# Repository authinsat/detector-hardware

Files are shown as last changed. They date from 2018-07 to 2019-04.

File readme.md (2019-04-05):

#American University ThinSat repository

American University Physics Department
Washington, DC

##Synopsis
This is the support repository for AU's ThinSat project, embarked upon in Spring 2018. Supported by VASpace, Twiggs Space Laboratories, XinaBox, the DC NASA Space Grant Consortium, and the Institute for Integrated Space Science and Technology (ISSTI).

Currently, the only materials housed in this repository are the PCB design files for the particle detector.

Initial PCB design from MIT's Cosmic Watch <https://github.com/spenceraxani/CosmicWatch-Desktop-Muon-Detector-v2>.

This project is licensed under the MIT License; please see license.md for more information.

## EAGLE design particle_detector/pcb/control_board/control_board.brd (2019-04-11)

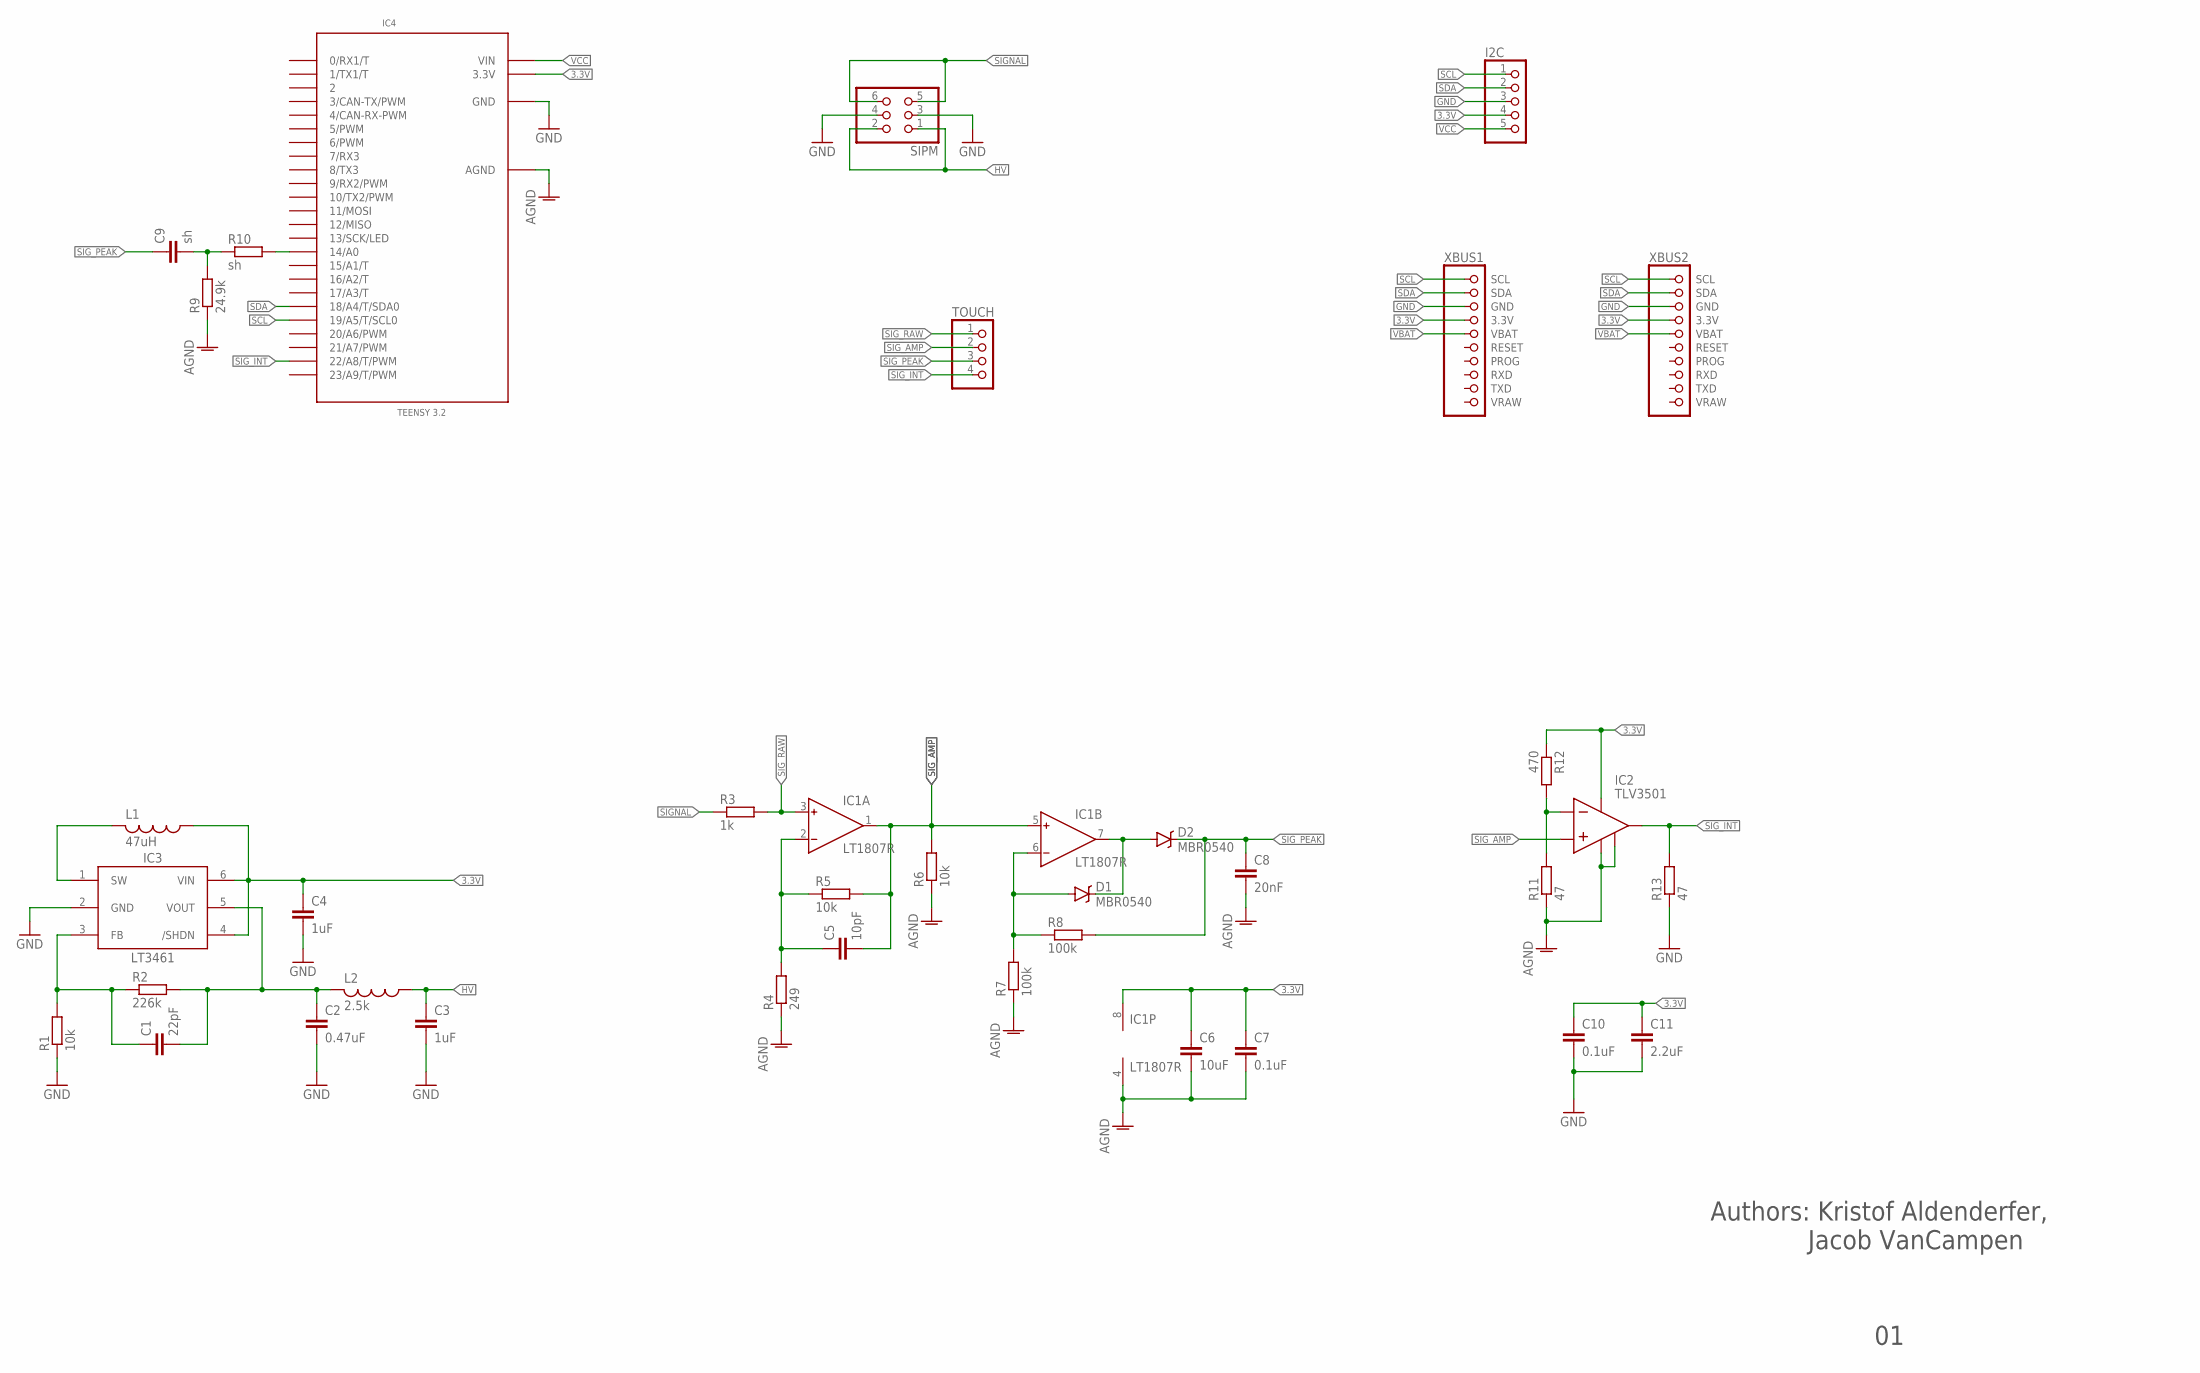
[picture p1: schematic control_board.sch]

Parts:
C1: 22pF; C0805K
C2: 0.47uF; C0805K
C3, C4: 1uF; C0805K
C5: 10pF; C0805K
C6: 10uF; C0805K
C7: 0.1uF; C0805K
C8: 20nF; C0805K
C9: sh; C0805K
C10: 0.1uF; C0805
C11: 2.2uF; C0805
D1, D2: MBR0540; SMA-DIODE
I2C: PINHD-1X5; 1X05
IC1: LT1807R; SO8
IC2: TLV3501; SOT23-6
IC3: LT3461; SOT23-6
IC4: TEENSY 3.2; TEENSY_3.2_NO_BOTTOM
L1: 47uH; L3225M
L2: 2.5k; L2012C
R1, R5, R6: 10k; M0805
R2: 226k; M0805
R3: 1k; M0805
R4: 249; M0805
R7, R8: 100k; M0805
R9: 24.9k; M0805
R10: sh; M0805
R11, R13: 47; M0805
R12: 470; M0805
SIPM: PINHD-2X3; 2X03
TOUCH: PINHD-1X4; 1X04
XBUS1, XBUS2: XINABOX-XBUS; XBUS_2X05_PAD

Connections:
3.3V: C4.1, C6.1, C7.1, C10.1, C11.1, I2C.4, IC1.8 (V+), IC2.P$4 (V+), IC3.4 (/SHDN), IC3.6 (VIN), IC4.3.3V, L1.1, R12.1, XBUS1.VCC (3.3V), XBUS2.VCC (3.3V)
AGND: C6.2, C7.2, C8.2, IC1.4 (V-), IC2.P$2 (V-), IC2.P$6 (SHDN), IC4.AGND, R4.1, R6.1, R7.1, R9.1, R11.1
GND: C2.2, C3.2, C4.2, C10.2, C11.2, I2C.3, IC3.2 (GND), IC4.GND, R1.1, R13.1, SIPM.3, SIPM.4, XBUS1.GND, XBUS2.GND
HV: C3.1, L2.1, SIPM.1, SIPM.2
unnamed: IC3.1 (SW), L1.2
unnamed: D1.C, D2.A, IC1.7 (OUT)
unnamed: C1.1, IC3.3 (FB), R1.2, R2.1
unnamed: D1.A, IC1.6 (IN-), R7.2, R8.1
unnamed: IC2.P$1 (IN-), R11.2, R12.2
unnamed: C1.2, C2.1, IC3.5 (VOUT), L2.2, R2.2
unnamed: C5.1, IC1.2 (IN-), R4.2, R5.1
unnamed: C9.2, R9.2, R10.1
unnamed: IC4.14/A0, R10.2
SCL: I2C.1, IC4.19/A5 (19/A5/T/SCL0), XBUS1.SCL, XBUS2.SCL
SDA: I2C.2, IC4.18/A4 (18/A4/T/SDA0), XBUS1.SDA, XBUS2.SDA
SIGNAL: R3.1, SIPM.5, SIPM.6
SIG_AMP: C5.2, IC1.1 (OUT), IC1.5 (IN+), IC2.P$3 (IN+), R5.2, R6.2, TOUCH.2
SIG_INT: IC2.P$5 (OUT), IC4.22/A8 (22/A8/T/PWM), R13.2, TOUCH.4
SIG_PEAK: C8.1, C9.1, D2.C, R8.2, TOUCH.3
SIG_RAW: IC1.3 (IN+), R3.2, TOUCH.1
VBAT: XBUS1.VBAT, XBUS2.VBAT
VCC: I2C.5, IC4.VIN

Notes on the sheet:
Authors: Kristof Aldenderfer, Jacob VanCampen

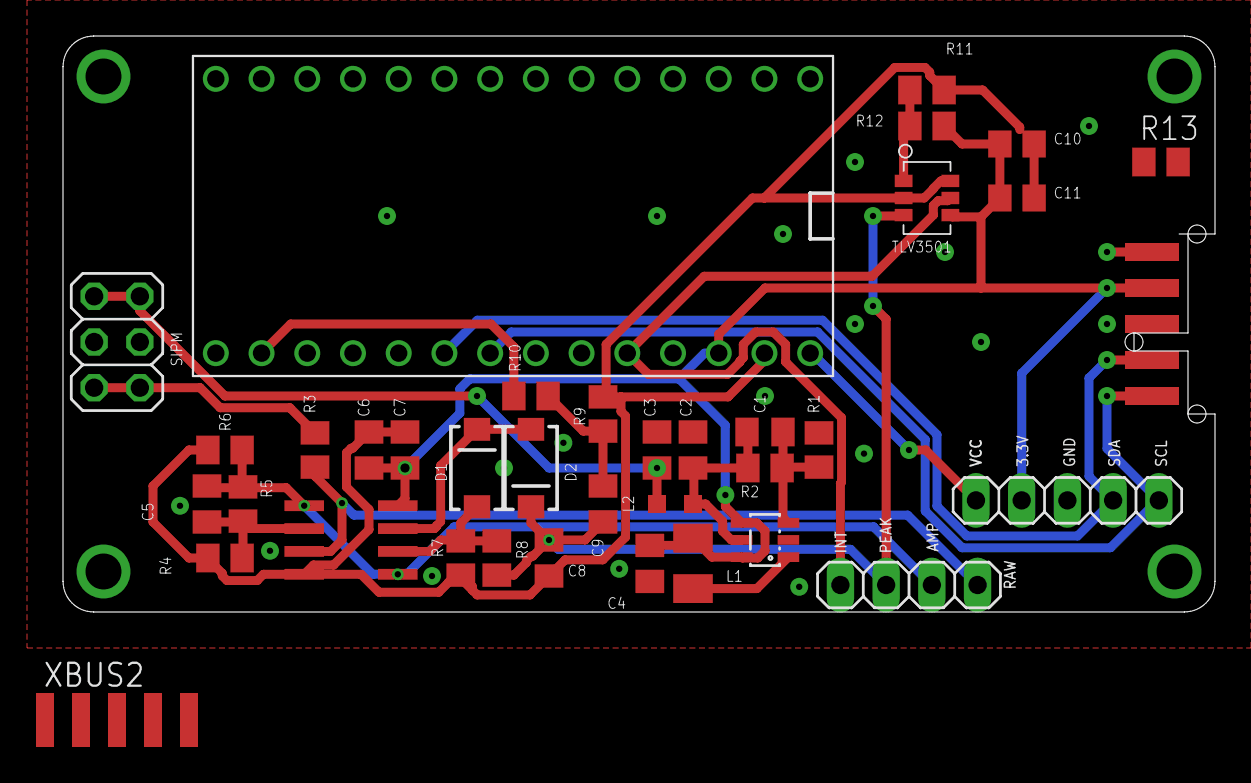
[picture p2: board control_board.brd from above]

Board: 2 copper layers, 64.0 x 32.0 mm, 37 parts (0 on the bottom side), 22 nets.

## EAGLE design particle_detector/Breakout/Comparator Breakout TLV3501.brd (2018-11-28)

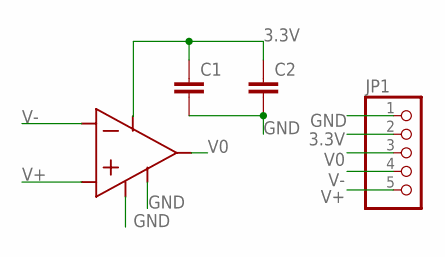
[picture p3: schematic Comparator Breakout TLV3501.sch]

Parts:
C1, C2: C-EUC0805; C0805
JP1: PINHD-1X5; 1X05
U$1: TLV3501; SOT23-6

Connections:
3.3V: C1.1, C2.1, JP1.2, U$1.P$4 (V+)
GND: C1.2, C2.2, JP1.1, U$1.P$2 (V-), U$1.P$6 (SHDN)
V0: JP1.3, U$1.P$5 (OUT)
V+: JP1.5, U$1.P$3 (IN+)
V-: JP1.4, U$1.P$1 (IN-)

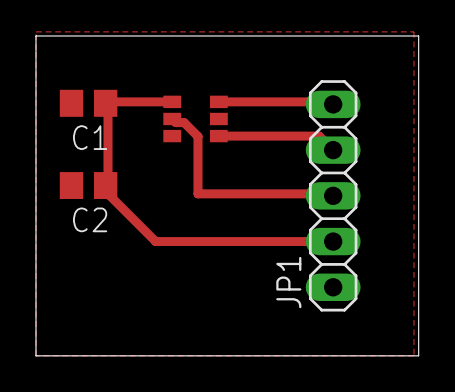
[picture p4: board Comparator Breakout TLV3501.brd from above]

Board: 2 copper layers, 21.3 x 17.8 mm, 4 parts (0 on the bottom side), 5 nets.

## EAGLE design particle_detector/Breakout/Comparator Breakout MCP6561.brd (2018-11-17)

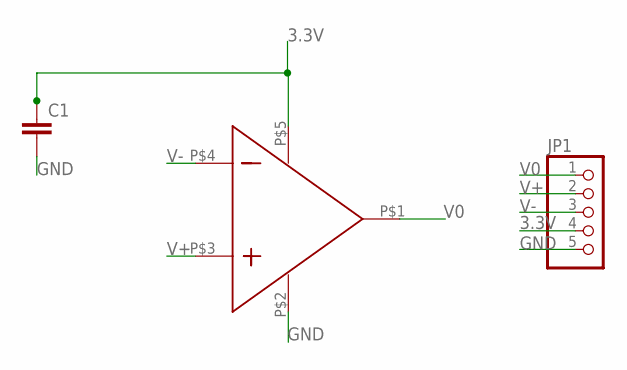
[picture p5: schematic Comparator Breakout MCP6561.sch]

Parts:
C1: C-EUC0805; C0805
JP1: PINHD-1X5; 1X05
U$1: MCP6561; SC70-5

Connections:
3.3V: C1.1, JP1.4, U$1.P$5 (VDD)
GND: C1.2, JP1.5, U$1.P$2 (VSS)
V0: JP1.1, U$1.P$1 (OUT)
V+: JP1.2, U$1.P$3 (IN+)
V-: JP1.3, U$1.P$4 (IN-)

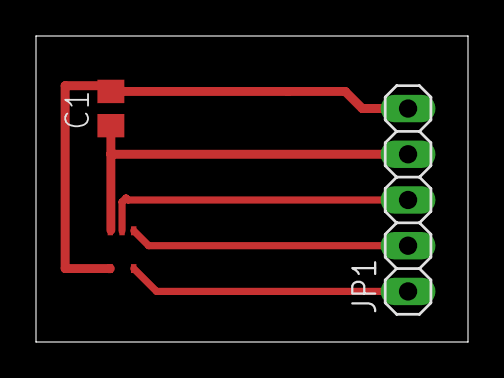
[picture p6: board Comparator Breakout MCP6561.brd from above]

Board: 2 copper layers, 24.0 x 17.0 mm, 3 parts (0 on the bottom side), 5 nets.

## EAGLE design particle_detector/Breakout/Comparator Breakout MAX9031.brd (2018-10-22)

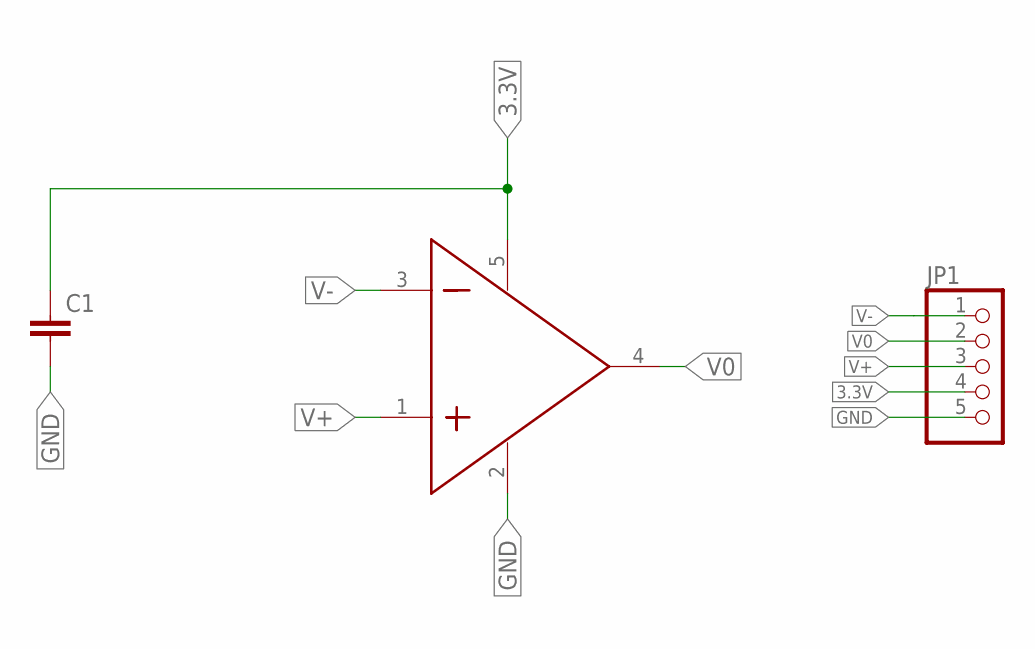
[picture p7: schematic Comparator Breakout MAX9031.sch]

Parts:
C1: C-EUC0805; C0805
JP1: PINHD-1X5; 1X05
U$1: MAX9031; SOT23-5

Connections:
3.3V: C1.1, JP1.4, U$1.5 (VDD)
GND: C1.2, JP1.5, U$1.2 (VSS)
V0: JP1.2, U$1.4 (OUT)
V+: JP1.3, U$1.1 (IN+)
V-: JP1.1, U$1.3 (IN-)

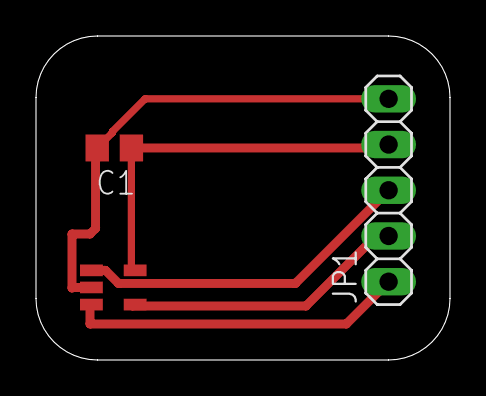
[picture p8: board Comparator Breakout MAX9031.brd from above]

Board: 2 copper layers, 23.0 x 18.0 mm, 3 parts (0 on the bottom side), 5 nets.

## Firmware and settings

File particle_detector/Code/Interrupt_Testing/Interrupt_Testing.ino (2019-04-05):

int sipm = A0; //can change pin later
unsigned int sipm_val = 0;
unsigned int sipm_thresh = 1000;
byte analog_res = 12;
char msg[128];
int count_pin = 4;
int div_pin = 5;
volatile bool is_it_time_to_sample = false;
volatile bool data_time = false;
int values[100] = {};
int count = 0;
int tot = 0;
int avg = 0;
int i = 0;


void setup() {
  analogReadResolution(analog_res);
  Serial.begin(115200);
  while(!Serial);
  Serial.println("Ready.");
  pinMode(count_pin, INPUT_PULLUP);
  attachInterrupt(count_pin, ISR_PULSE, FALLING);
  pinMode(div_pin, INPUT_PULLUP);
  attachInterrupt(div_pin, ISR_SEND, FALLING);
}



void loop() {
  if (is_it_time_to_sample == true) {
    sipm_val = analogRead(sipm);
    Serial.println(sipm_val);
    values[count] = sipm_val;
    count++;
    is_it_time_to_sample = false;
  }
  if (data_time == true){
    for(i = 0; i < count; i = i + 1){
      tot = tot + values[i];
      }
    avg = tot/count;
    Serial.println("number:");
    Serial.println(count);
    Serial.println("average:");
    Serial.println(avg);
    count = 0;
    tot = 0;
    data_time = false;
  }
}



void ISR_PULSE() {
  is_it_time_to_sample = true;
}



void ISR_SEND() {
  data_time = true;
  }

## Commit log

2018-06-19 add start of detector sch
    [detector.sch]
2018-06-21 complete SiPM and HV schs, partial completion of amplifier, hold schs
    [detector.sch]
2018-06-21 complete first pass of sch
    [detector.sch]
2018-06-22 change EDA name to split boards
    [detector_full.brd, detector_full.sch]
2018-06-22 add control board eda
    [control_board.brd, control_board.sch]
2018-06-26 update EDA with xinabox footprint; board done, awaiting fabhouse confirmation
    [control_board.brd, control_board.sch]
2018-06-27 clean up traces
    [control_board.brd]
2018-07-09 fix AGNd and 3.3V issue; needs DRC
    [control_board.brd, control_board.sch]
2018-07-20 move to eagle project; fix vcc/3.3v and ind package; remove full board design
    [control_board.brd, control_board.sch, detector_full.brd]
2018-08-17 add two breakout board edas
    [Comparator Breakout MAX9031.brd, Comparator Breakout MAX9031.sch, Comparator Breakout MCP6541.brd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]
2018-08-20 Fixed Traces on MAX9031
    [Comparator Breakout MAX9031.brd]
2018-08-20 Fixed the Traces on the MCP6541
    [Comparator Breakout MCP6541.brd]
2018-10-18 revised boards from a while ago
    [Comparator Breakout MAX9031.brd, Comparator Breakout MAX9031.sch, Comparator Breakout MCP6541.brd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]
2018-10-22 Updated footprint with longer pads
    [Comparator Breakout MAX9031.brd, Comparator Breakout MAX9031.sch, Comparator Breakout MCP6541.brd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]
2018-11-17 NEW BOARDS HECK YEAH
    [Comparator Breakout MCP6561.brd, Comparator Breakout MCP6561.sch, Comparator Breakout TLV3501.brd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]
2018-11-28 Fixed problematic TLVInsect comparator
    [Comparator Breakout TLV3501.brd, Comparator Breakout TLV3501.sch]
2018-11-29 Stuck the TLV on there, not finished
    [control_board.brd, control_board.sch]
2018-11-30 reroute traces and fix footprint for TLV chip
    [control_board.brd, control_board.sch]
2018-11-30 remove VCC traces to DC-DC booster; 3.3V traces remain unrouted
    [control_board.brd, control_board.sch]
2018-12-02 adjust comparator footprint; route 3.3V traces. send to fab
    [control_board.brd, control_board.sch]
2019-04-11 begin fix of INT section
    [control_board.brd, control_board.sch]

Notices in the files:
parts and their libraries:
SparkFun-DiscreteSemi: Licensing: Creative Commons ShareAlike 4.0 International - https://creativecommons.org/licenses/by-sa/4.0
